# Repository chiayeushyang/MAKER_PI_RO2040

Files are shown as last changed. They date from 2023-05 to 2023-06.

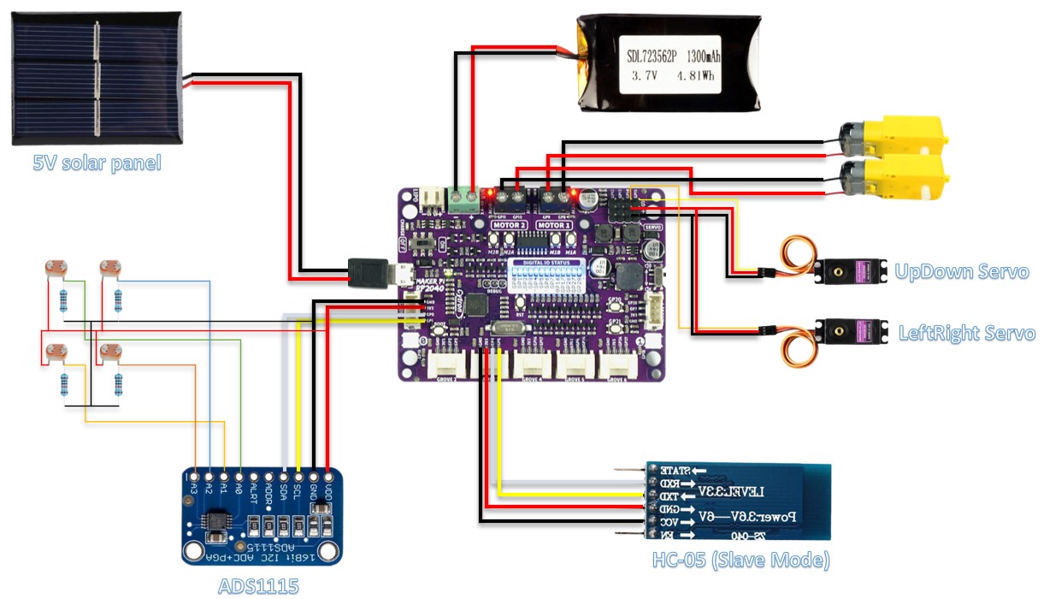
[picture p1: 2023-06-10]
Solar Tracking Car .jpg

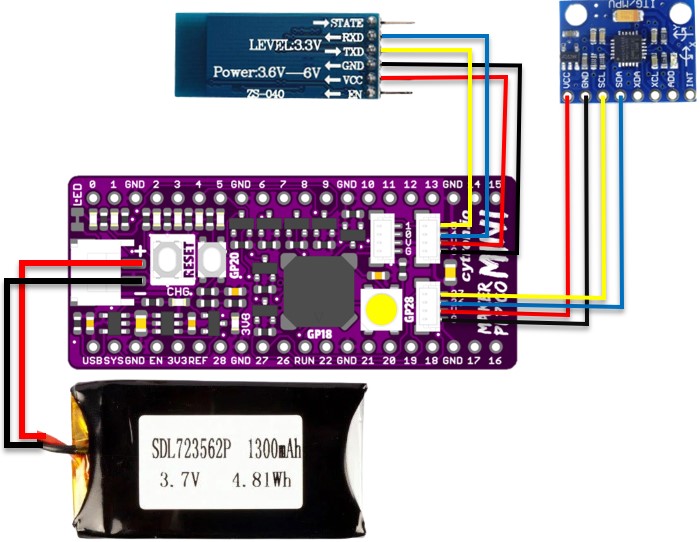
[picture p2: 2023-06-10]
remote_control.jpg

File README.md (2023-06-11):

# SunTrackRover

## Demostrate Video
https://www.facebook.com/100002367838790/videos/209715711489783/

## Remote Control
remote_control

## Solar Tracking Car
Solar Tracking Car

------------------------------------------------------------------------------------------------------------------------

# STL file
## Remote Control
case-2
case-1

## Solar Trackers
solar-trackers-1
solar-trackers-2

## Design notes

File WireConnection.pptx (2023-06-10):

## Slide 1

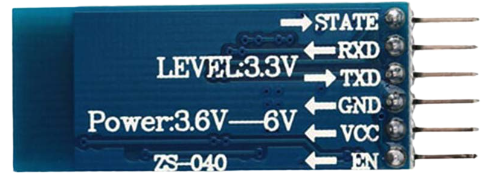
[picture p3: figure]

MPU6050

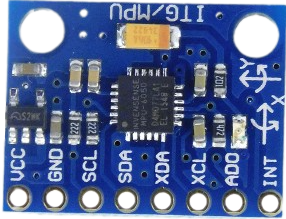
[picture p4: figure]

HC-05 (Master Mode)

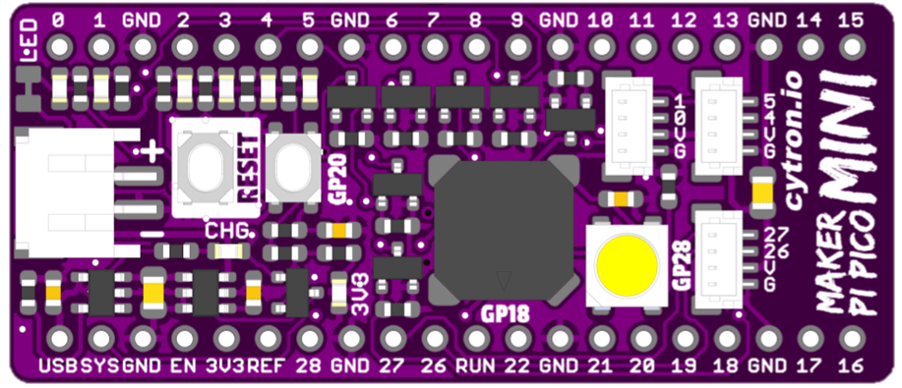
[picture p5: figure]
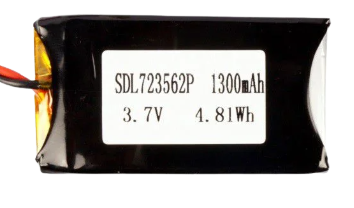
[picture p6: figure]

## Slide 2

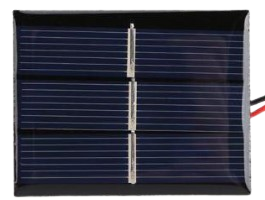
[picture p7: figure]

5V solar panel

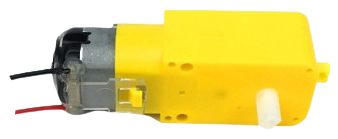
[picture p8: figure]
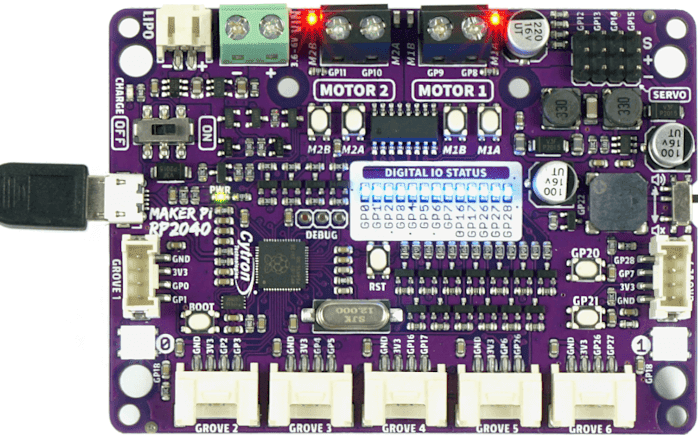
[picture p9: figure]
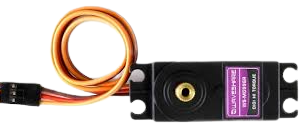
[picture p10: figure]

UpDown Servo

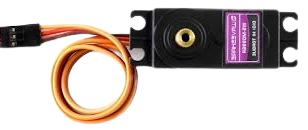
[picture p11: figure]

LeftRight Servo

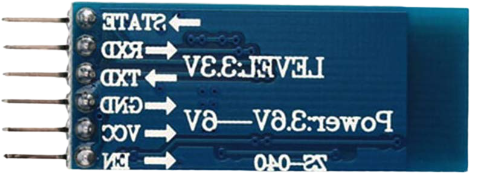
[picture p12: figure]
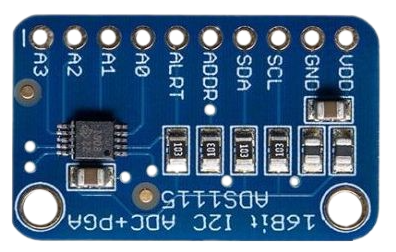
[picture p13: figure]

ADS1115

HC-05 (Slave Mode)

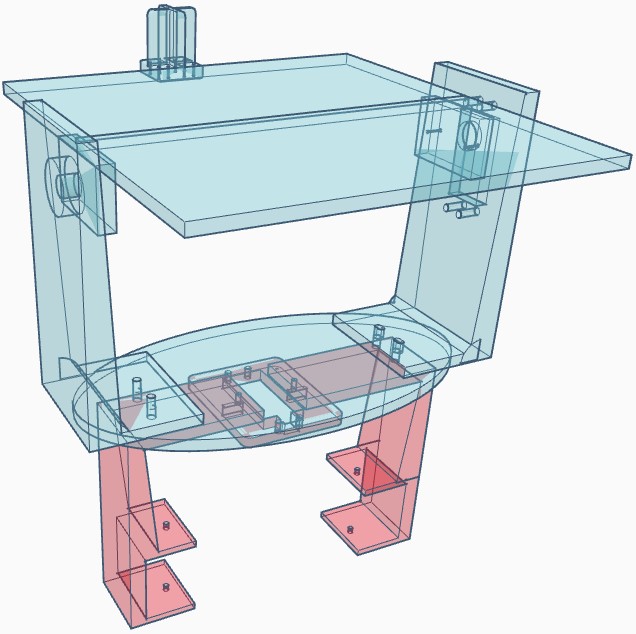
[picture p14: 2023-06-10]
STL File/Solar Trackers/solar-trackers-1.jpg

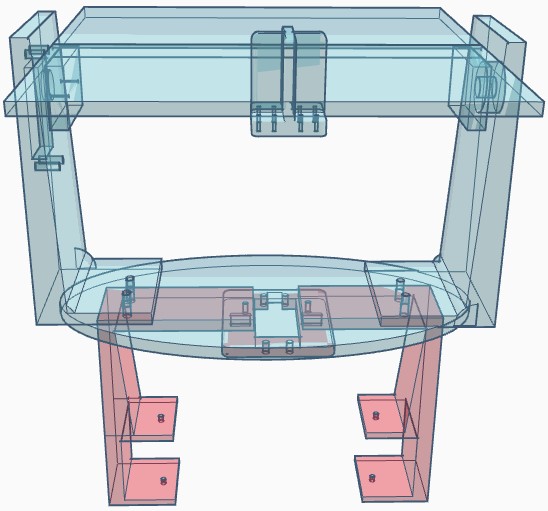
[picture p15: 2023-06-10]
STL File/Solar Trackers/solar-trackers-2.jpg

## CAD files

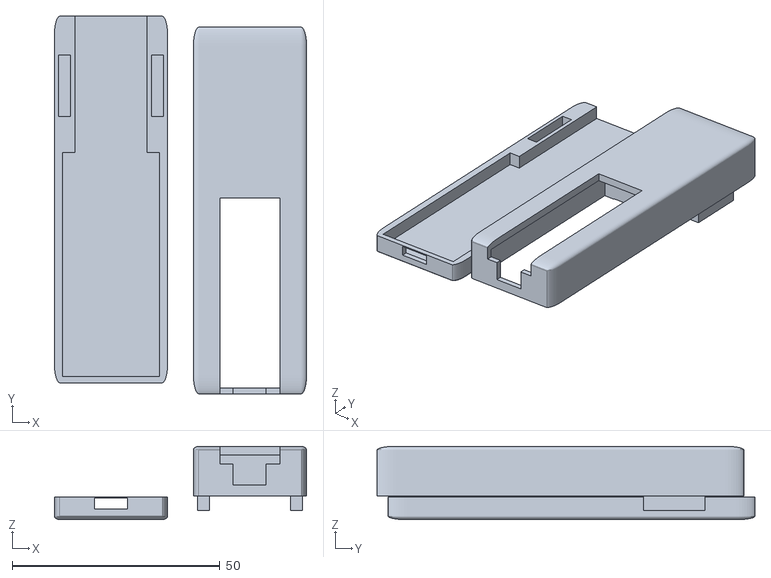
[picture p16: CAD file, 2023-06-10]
STL File/remote_case.stl
60.8 x 91.1 x 17.7

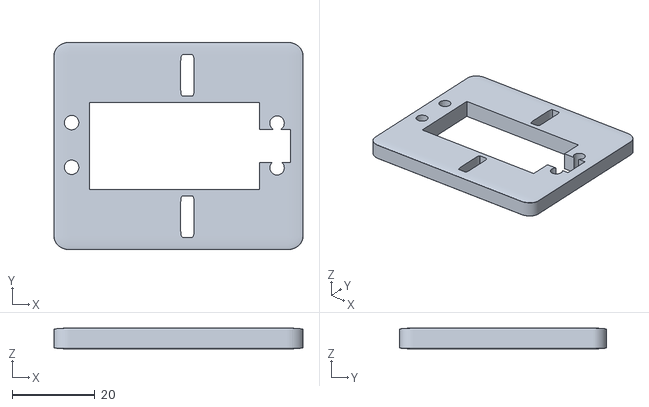
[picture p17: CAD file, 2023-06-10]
STL File/Solar Trackers/Separate/servo-adapter.stl
60.0 x 50.0 x 5.00

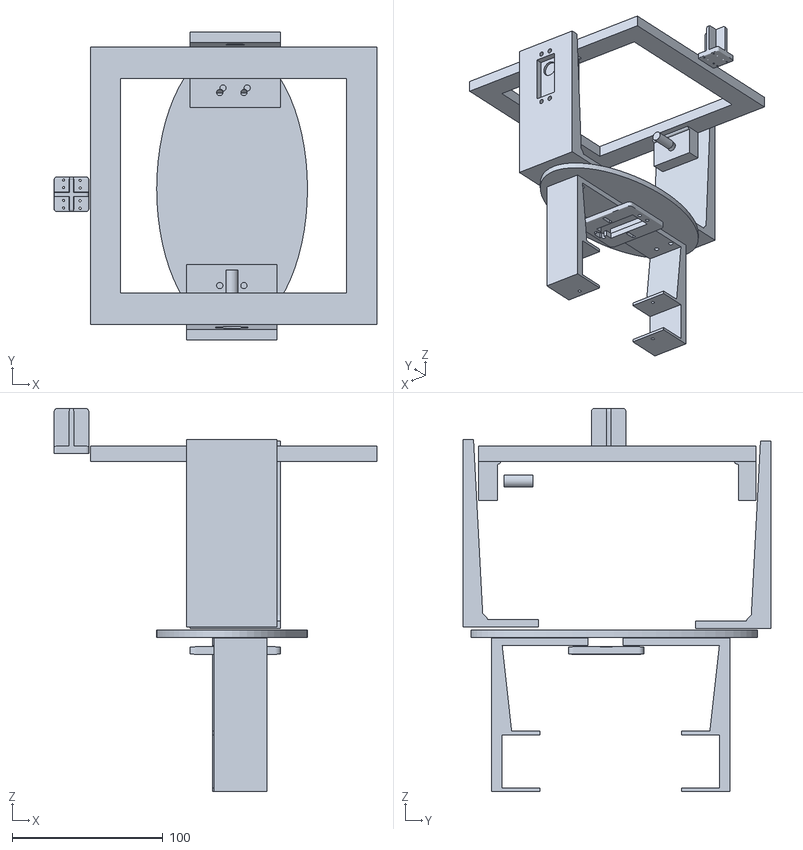
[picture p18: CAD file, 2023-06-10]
STL File/Solar Trackers/solar trackers(9part).stl
214.0 x 204.3 x 254.0

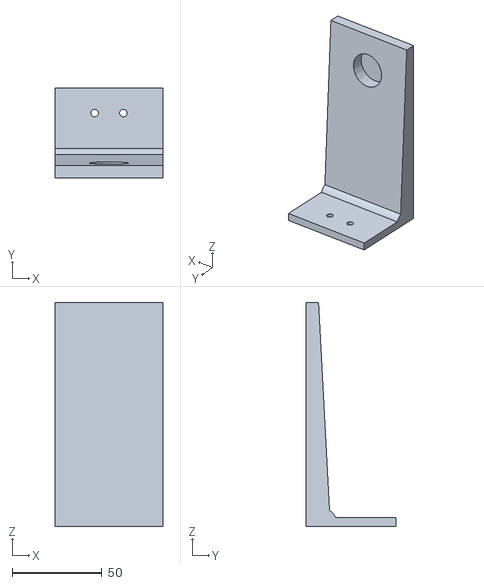
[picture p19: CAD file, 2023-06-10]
STL File/Solar Trackers/Separate/bearing-holder.stl
60.0 x 50.0 x 124.5

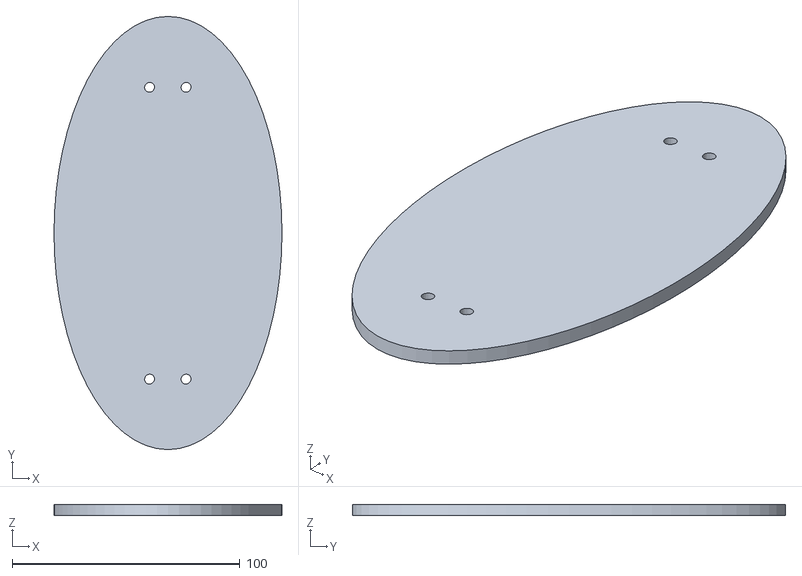
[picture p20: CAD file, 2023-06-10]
STL File/Solar Trackers/Separate/base.stl
100.0 x 190.0 x 5.00

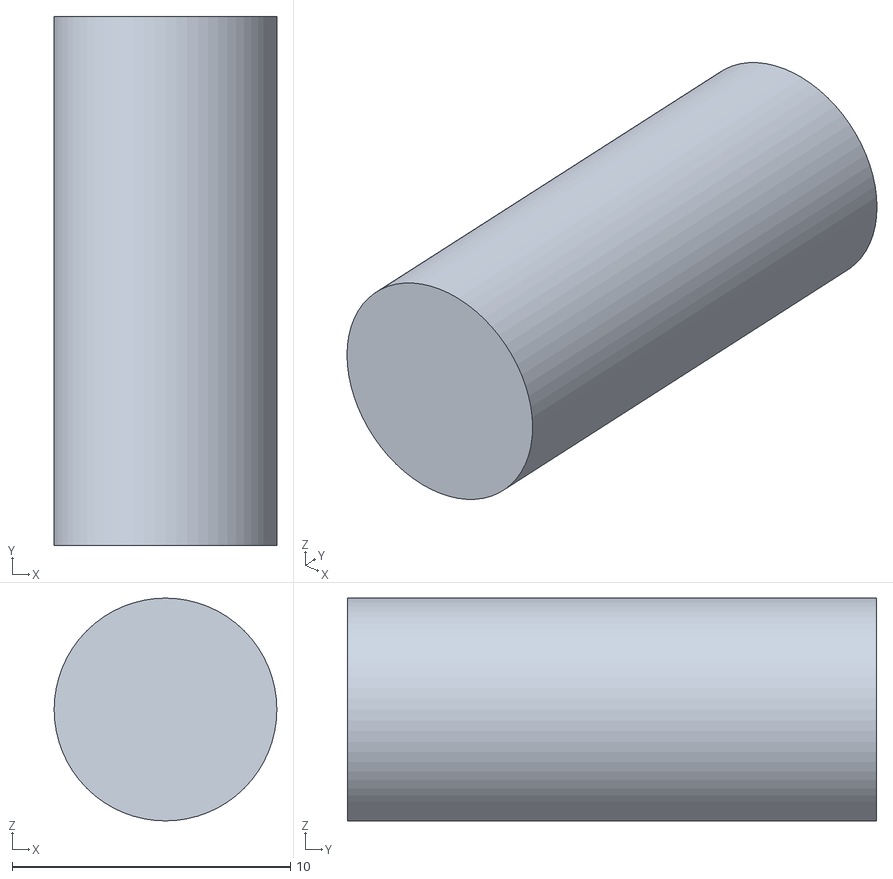
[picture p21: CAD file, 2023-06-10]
STL File/Solar Trackers/Separate/bearing-connect.stl
8.00 x 19.0 x 8.00

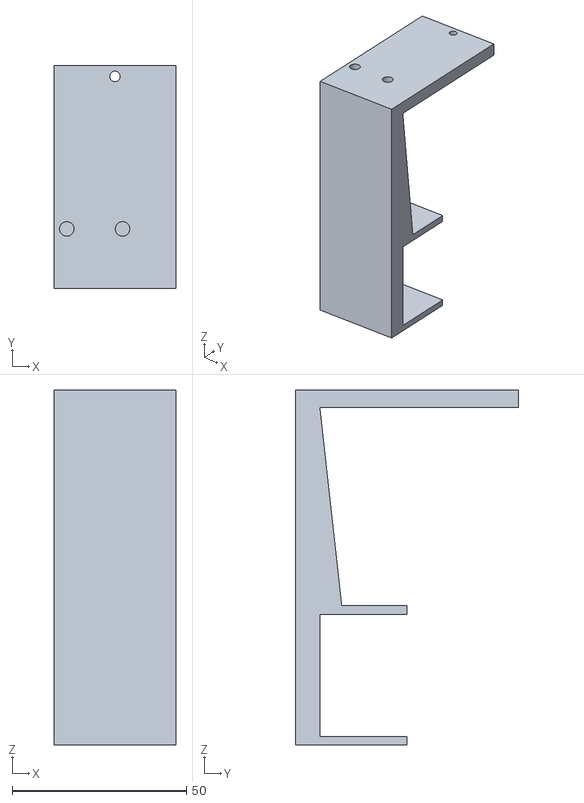
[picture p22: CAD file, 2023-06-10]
STL File/Solar Trackers/Separate/car-connector-1.stl
35.0 x 64.0 x 101.9

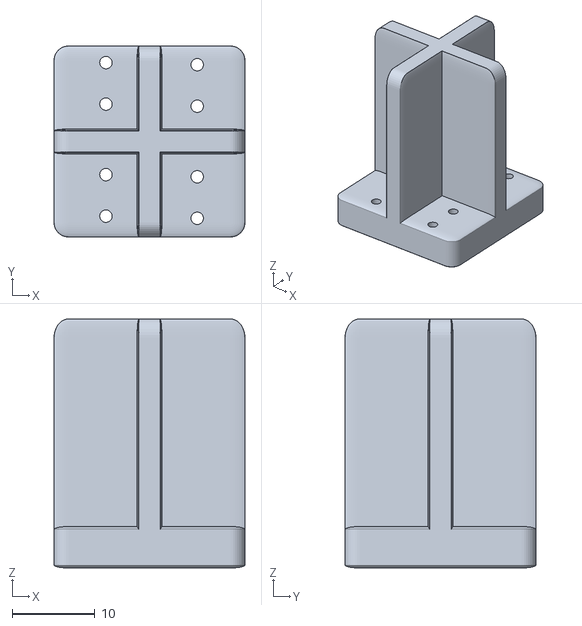
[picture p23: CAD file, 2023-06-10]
STL File/Solar Trackers/Separate/LDR-adapter.stl
23.0 x 23.0 x 30.0

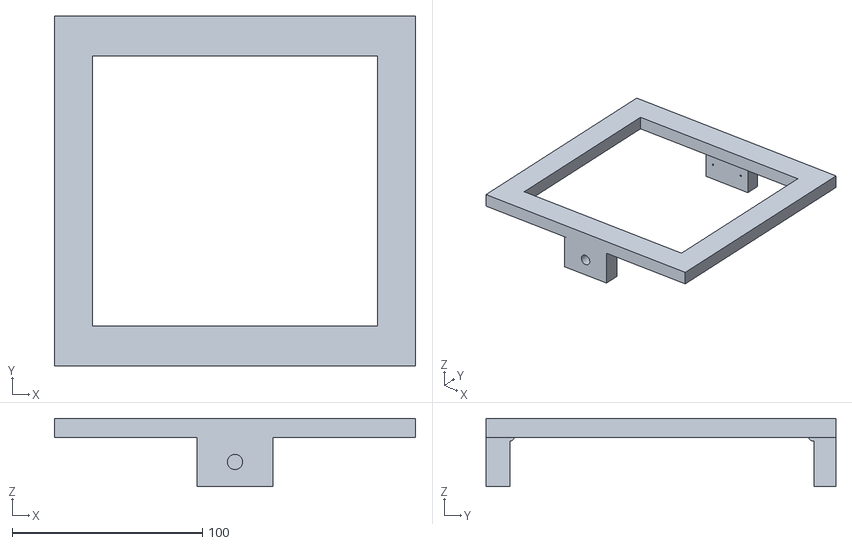
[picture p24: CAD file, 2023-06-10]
STL File/Solar Trackers/Separate/top-base.stl
190.0 x 184.0 x 36.0

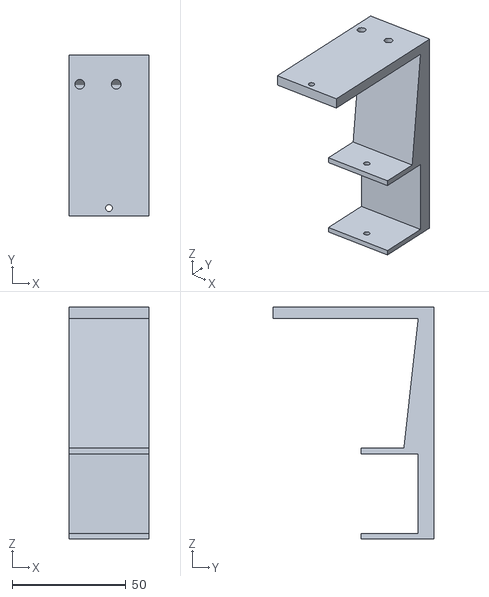
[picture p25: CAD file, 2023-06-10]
STL File/Solar Trackers/Separate/car-connector-2.stl
35.0 x 70.8 x 101.9

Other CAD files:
STL File/Solar Trackers/Separate/servo-holder.stl

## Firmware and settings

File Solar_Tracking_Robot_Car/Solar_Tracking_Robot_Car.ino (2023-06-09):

#include <Adafruit_NeoPixel.h>
#include <Servo.h>
#include "CytronMotorDriver.h"
#include "ADS1X15.h"

//VCC -> 3.3v
//GND -> GND
//RX(5) -> HC-05 TX
//TX(4) -> HC-05 RX
#define RX_PIN 5
#define TX_PIN 4
#define NUM_LEDS 2
#define LED_PIN 18


int Button = 20;

int buttonState = 0;

boolean buttonFlag = false;

char val;

int16_t top_r;
int16_t top_l;
int16_t bot_r;
int16_t bot_l;
int avgtop;
int avgbot;
int avgleft;
int avgright;
int diffelev;
int diffazi;

int DEFAULT_ANGLE = 120;
int THRESHOLD_VALUE = 1000;
int SERVO_MIN = 20;
int SERVO_MAX = 160;
int SERVO_SMOOTH = 15;

CytronMD motor1(PWM_PWM, 8, 9);   // PWM 1A = Pin 8, PWM 1B = Pin 9.
CytronMD motor2(PWM_PWM, 10, 11); // PWM 2A = Pin 10, PWM 2B = Pin 11.

Adafruit_NeoPixel pixels(NUM_LEDS, LED_PIN, NEO_GRB + NEO_KHZ800);

ADS1115 ADS(0x48, &Wire); //SCL 0, SCA 0 || &Wire1 -> SCL 1, SDA 1

Servo servo_leftright;
Servo servo_updown;

void setup() {

  Serial.begin(9600);

  Serial2.setRX(RX_PIN);
  Serial2.setTX(TX_PIN);

  Serial2.begin(9600);

  pinMode(Button, INPUT_PULLUP);

  //Neopixle LED
  pixels.begin();
  pixels.show(); // Initialize all pixels to off
  pixels.setBrightness(20);
}

void loop() {

  if (Serial.available()) {
    Serial2.write(Serial.read());
  }

  if (Serial2.available()) {
    val = Serial2.read();
  }

  switch (val)
  {
    case 'F':
      // Perform forward operation
      //  Serial.println("Car moving forward");

      //  for (int i = 0; i < NUM_LEDS; i++) {
      //   pixels.setPixelColor(i, pixels.Color(0, 255, 0));
      //  }
      // pixels.show();
      // delay(100);

      // pixels.clear();
      // pixels.show();

      motor1.setSpeed(-255);
      motor2.setSpeed(-255);
      break;

    case 'B':
      // Perform backward operation
      //      Serial.println("Car moving backward");

      //      for (int i = 0; i < NUM_LEDS; i++) {
      //        pixels.setPixelColor(i, pixels.Color(0, 0, 255));
      //      }
      //      pixels.show();
      //      delay(100);
      //
      //      pixels.clear();
      //      pixels.show();

      motor1.setSpeed(255);
      motor2.setSpeed(255);
      break;

    case 'L':
      // Perform left operation
      //      Serial.println("Car turning left");
      //
      //      pixels.setPixelColor(0, pixels.Color(0, 0, 255));
      //
      //      pixels.show();
      //      delay(100);
      //
      //      pixels.clear();
      //      pixels.show();

      motor1.setSpeed(255);
      motor2.setSpeed(-255);

      break;

    case 'R':
      // Perform right operation
      //      Serial.println("Car turning right");
      //
      //      pixels.setPixelColor(1, pixels.Color(0, 0, 255));
      //
      //      pixels.show();
      //      delay(100);
      //
      //      pixels.clear();
      //      pixels.show();

      motor1.setSpeed(-255);
      motor2.setSpeed(255);

      break;

    case 'S':
      // Perform stop operation
      //      Serial.println("Car stopped");
      //
      //      for (int i = 0; i < NUM_LEDS; i++) {
      //        pixels.setPixelColor(i, pixels.Color(255, 10, 10));
      //      }
      //      pixels.show();
      //      delay(100);
      //
      //      pixels.clear();
      //      pixels.show();

      motor1.setSpeed(0);
      motor2.setSpeed(0);

      break;

    case 'O':
      // Perform off operation
      Serial.println("Car turned off");

      for (int i = 0; i < NUM_LEDS; i++) {
        pixels.setPixelColor(i, pixels.Color(191, 39, 191));
      }
      pixels.show();
      delay(100);

      pixels.clear();
      pixels.show();

      motor1.setSpeed(0);
      motor2.setSpeed(0);

      break;
  }
}

// Running on core1
void setup1() {

  //ADS1115
  ADS.begin(0, 1);   // SDA (Pin 0), SCL(Pin 1)
  ADS.setDataRate(7);  // 0 = slow   4 = medium   7 = fast
  ADS.setMode(0);      // continuous mode
  ADS.setGain(1);

  //Servo
  servo_leftright.attach(14);
  servo_updown.attach(15);

  servo_leftright.write(110);
  servo_updown.write(110);
}

void loop1() {
  automaticsolartracker();
}

void automaticsolartracker() {
  top_r = ADS.readADC(0); //top right
  bot_r = ADS.readADC(1); //bot right
  top_l = ADS.readADC(2); //top left
  bot_l = ADS.readADC(3); //bot left

  avgtop = (top_r + top_l) / 2;
  avgbot = (bot_r + bot_l) / 2;
  avgleft = (top_l + bot_l) / 2;
  avgright = (top_r + bot_r) / 2;

  diffelev = avgtop - avgbot;
  diffazi = avgright - avgleft;

  if (abs(diffazi) >= THRESHOLD_VALUE) {
    if (diffazi < 0) {
      if (servo_leftright.read() < SERVO_MAX) {
        servo_leftright.write((servo_leftright.read() + 2));
        delay(SERVO_SMOOTH);
      }
    }
    if (diffazi > 0) {
      if (servo_leftright.read() > SERVO_MIN) {
        servo_leftright.write((servo_leftright.read() - 2));
        delay(SERVO_SMOOTH);
      }
    }
  }

  if (abs(diffelev) >= THRESHOLD_VALUE) {
    if (diffelev > 0) {
      if (servo_updown.read() < SERVO_MAX) {
        servo_updown.write((servo_updown.read() + 2));
        delay(SERVO_SMOOTH);
      }
    }
    if (diffelev < 0) {
      if (servo_updown.read() > SERVO_MIN) {
        servo_updown.write((servo_updown.read() - 2));
        delay(SERVO_SMOOTH);
      }
    }
  }
}

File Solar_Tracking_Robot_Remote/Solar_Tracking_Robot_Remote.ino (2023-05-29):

#include "Wire.h"
#include <MPU6050_light.h>
#include <SoftwareSerial.h>
#include <Adafruit_NeoPixel.h>

#define LED_PIN 28
#define NUM_LEDS 1

#define Min_Angle 30
MPU6050 mpu(Wire1);
Adafruit_NeoPixel pixels(NUM_LEDS, LED_PIN, NEO_GRB + NEO_KHZ800);

#define RX_PIN 5
#define TX_PIN 4

const int powerButton = 20;
int powerState = HIGH;
int prevPowerState = HIGH;
boolean carOn = false;

unsigned long buttonPressTime = 0;
const unsigned long longPressDuration = 500; // Adjust the long-press duration as needed (in milliseconds)

char previousCommand = '\0'; // Previous command sent to the control

void setup() {
  Serial2.setRX(RX_PIN);
  Serial2.setTX(TX_PIN);
  Serial2.begin(9600);

  Wire1.setSDA(26);
  Wire1.setSCL(27);
  Serial.begin(9600);
  Wire1.begin();

  byte status = mpu.begin();
  Serial.print(F("MPU6050 status: "));
  Serial.println(status);
  while (status != 0) { } // stop everything if could not connect to MPU6050

  Serial.println(F("Calculating offsets, do not move MPU6050"));
  delay(1000);
  mpu.calcOffsets(true, true); // gyro and accelero
  Serial.println("Done!\n");

  pinMode(powerButton, INPUT_PULLUP);

  pixels.begin();
  pixels.show(); // Initialize all pixels to off
}

void loop() {
  mpu.update();
  delay(50);
  powerState = digitalRead(powerButton);

  if (powerState != prevPowerState) {
    delay(20);

    if (powerState == LOW) {
      buttonPressTime = millis(); // Record button press time
    } else {
      unsigned long buttonReleaseTime = millis();
      unsigned long buttonPressDuration = buttonReleaseTime - buttonPressTime;

      if (buttonPressDuration < longPressDuration) {
        toggleCarPower(); // Perform short press action
      } else {
        performLongPressAction(); // Perform long press action
      }
    }

    prevPowerState = powerState; // Update the previous power state
  }

  if (carOn) {
    pixels.setBrightness(20);

    for (int i = 0; i < NUM_LEDS; i++) {
      pixels.setPixelColor(i, pixels.Color(0, 255, 0)); // Set pixel color to green (RGB)
    }

    pixels.show(); // Update the strip

    int angleX = mpu.getAccAngleX();
    int angleY = mpu.getAccAngleY();
    
    char commandToSend = '\0'; // Command to be sent to the control

    if (angleY < -Min_Angle) {
      commandToSend = 'B'; // Send backward command
    } else if (angleY > Min_Angle) {
      commandToSend = 'F'; // Send forward command
    } else if (angleX > Min_Angle) {
      commandToSend = 'R'; // Send right command
    } else if (angleX < -Min_Angle) {
      commandToSend = 'L'; // Send left command
    } else {
      commandToSend = 'S'; // Send stop command
    }

    if (commandToSend != previousCommand) {
      Serial2.write(commandToSend); // Send the command to the control
      Serial.println(commandToSend);
      previousCommand = commandToSend; // Update the previous command
    }
  } else {
    if (previousCommand != 'O') {
      Serial2.write('O'); // Send off command
      Serial.println('O');
      previousCommand = 'O'; // Update the previous command
    }

    pixels.setBrightness(50);

    for (int i = 0; i < NUM_LEDS; i++) {
      pixels.setPixelColor(i, pixels.Color(255, 0, 0)); // Set pixel color to red (RGB)
    }
    pixels.show(); // Update the strip
  }
}

void toggleCarPower() {
  if (carOn) {
    carOn = false;
    if (previousCommand != '0') {
      Serial2.write('0'); // Send off command
      Serial.println("Car turned OFF");
      previousCommand = '0'; // Update the previous command
    }
  } else {
    carOn = true;
    if (previousCommand != '1') {
      Serial2.write('1'); // Send on command
      Serial.println("Car turned ON");
      previousCommand = '1'; // Update the previous command
    }
  }
}

void performLongPressAction() {
  for (int i = 0; i < 3; i++) {
    delay(300);
    for (int i = 0; i < NUM_LEDS; i++) {
      pixels.setPixelColor(i, pixels.Color(255, 0, 0)); // Set pixel color to red (RGB)
    }
    pixels.show(); // Update the strip
    delay(300);
    for (int i = 0; i < NUM_LEDS; i++) {
      pixels.setPixelColor(i, pixels.Color(0, 0, 0)); // Set pixel color to off (RGB)
    }
    pixels.show(); // Update the strip
    delay(300);
    for (int i = 0; i < NUM_LEDS; i++) {
      pixels.setPixelColor(i, pixels.Color(0, 0, 255)); // Set pixel color to blue (RGB)
    }
    pixels.show(); // Update the strip
    delay(300);
    for (int i = 0; i < NUM_LEDS; i++) {
      pixels.setPixelColor(i, pixels.Color(0, 0, 0)); // Set pixel color to off (RGB)
    }
    pixels.show(); // Update the strip
  }
  NVIC_SystemReset();
}

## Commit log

2023-05-22 Modify ADC file
2023-05-25 HC-05 master able to control by press button
2023-05-26 add I2C basic
2023-05-29 some correction and basic fuction on car
    [HC-05_Slave.ino, NEOPIXLE.ino, Solar_Tracking_Robot.ino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]
2023-06-04 solar trackers work but got some bug
    [ADS1115.ino, Solar_Tracking_Robot_Car.ino]
2023-06-10 remote control wire connection
2023-06-10 Add wire connection
2023-06-10 add stl file for solar trackers
    [LDR-adapter.stl, base.stl, bearing-connect.stl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]
